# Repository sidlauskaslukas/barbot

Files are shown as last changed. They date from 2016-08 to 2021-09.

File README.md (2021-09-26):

# Barbot

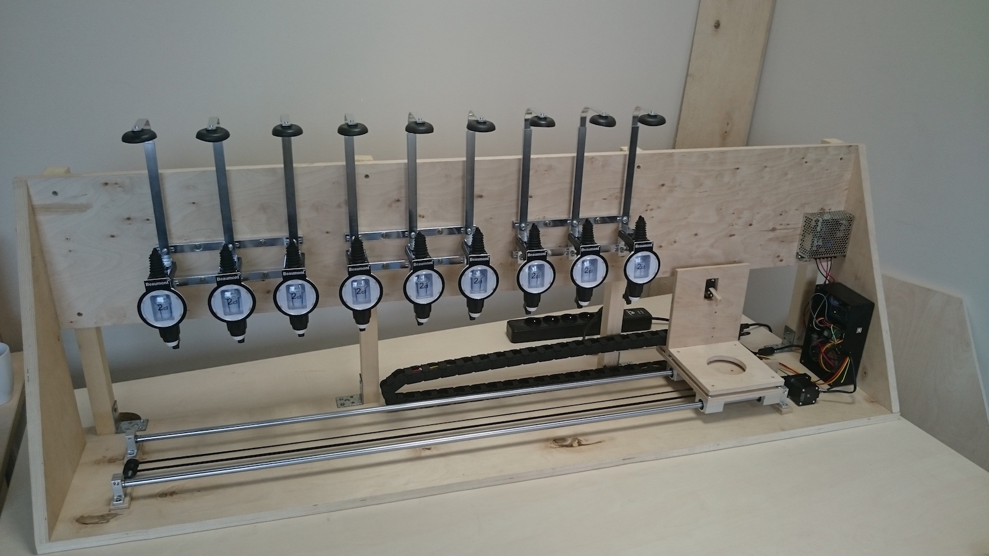
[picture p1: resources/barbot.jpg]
Barbot


Barbot is an open source Arduino cocktail mixing robot controlled with the hybrid mobile app via Bluetooth. It has been designed to hold up to 9 bottles of ingredients for making the cocktails, dispensing the correct amount from each to mix your cocktail of choice.

Cocktails can be chosen using the mobile app (available for iOS and Android) that connects to the Barbot via Bluetooth. In the app you can also enable/disable ingredients, change the position of each ingredient, edit the recipes and change the amount of each ingredient used in the cocktails and so on.

You can check how it works [here](https://youtu.be/1JVnOlu0Daw).

## Getting started

### Requirements
* Node v7.0.0 (I would recommend installing using Nvm [ [installing NVM](https://github.com/nvm-sh/nvm#installing-and-updating) ])
* Android SDK tools [ [installing Cordova requirements](https://cordova.apache.org/docs/en/latest/guide/platforms/android/#installing-the-requirements) ] or Xcode depending on which platform you want to use
* Arduino IDE

### Client
* Clone this repository
* Install Node version 7.0.0 `nvm install 7.0.0`
* Switch to Node version 7.0.0 `nvm use 7.0.0`
* From the client directory, run `npm install`
* Install Cordova 6.3.0 globally `npm install -g cordova@6.3.0`
* Install Ionic CLI 2.2.3 globally `npm install -g ionic@2.2.3`
* Run `ionic serve` in a terminal from the `client` directory
* At this point, Ionic CLI should open the app in your browser

### Barbot
* Clone this repository
* Start the Arduino IDE and open the `Barbot.ino`
* In Arduino IDE, select your board from the `Tools -> Board` menu (right now we're not supporting other boards than Arduino Mega)
* Select the serial port to which Arduino is connected from the `Tools -> Serial Port` menu
* Click the Verify button to see that the code is ok
* Click the Upload button
* If all goes well, that's it

## Required parts
* NEMA 17 stepper motor
* Pololu A4988 stepper driver
* Hitec HS-7955TG servo motor
* Pololu Micro Maestro 6-Channel servo controller
* Bluetooth module HC-05
* GT2 6mm wide timing belt
* GT2 timing pulley 20 teeth 5mm bore
* Timing belt bearing
* 2 x Chrome plated round rail 1200mm x 12mm
* 4 x SK12 12mm bore linear rail shaft support
* 4 x SC12UU aluminium pillow block housing
* 9 x 40ml Beaumont Metrix SL spirit measure
* 3 x Wall 3 bottle rack
* Endstop microswitch
* Arduino Mega 2560
* Cable carrier
* DC-DC converter (12V to 5V)
* AC power supply 12V (6.67A)

### List of 3D parts used in this project
* [NEMA 17 mount](https://www.thingiverse.com/thing:5391)
* [Adjustable belt holder](https://www.thingiverse.com/thing:745934)
* [Idler pulley mount](https://www.thingiverse.com/thing:1225670)

## Wiring diagram
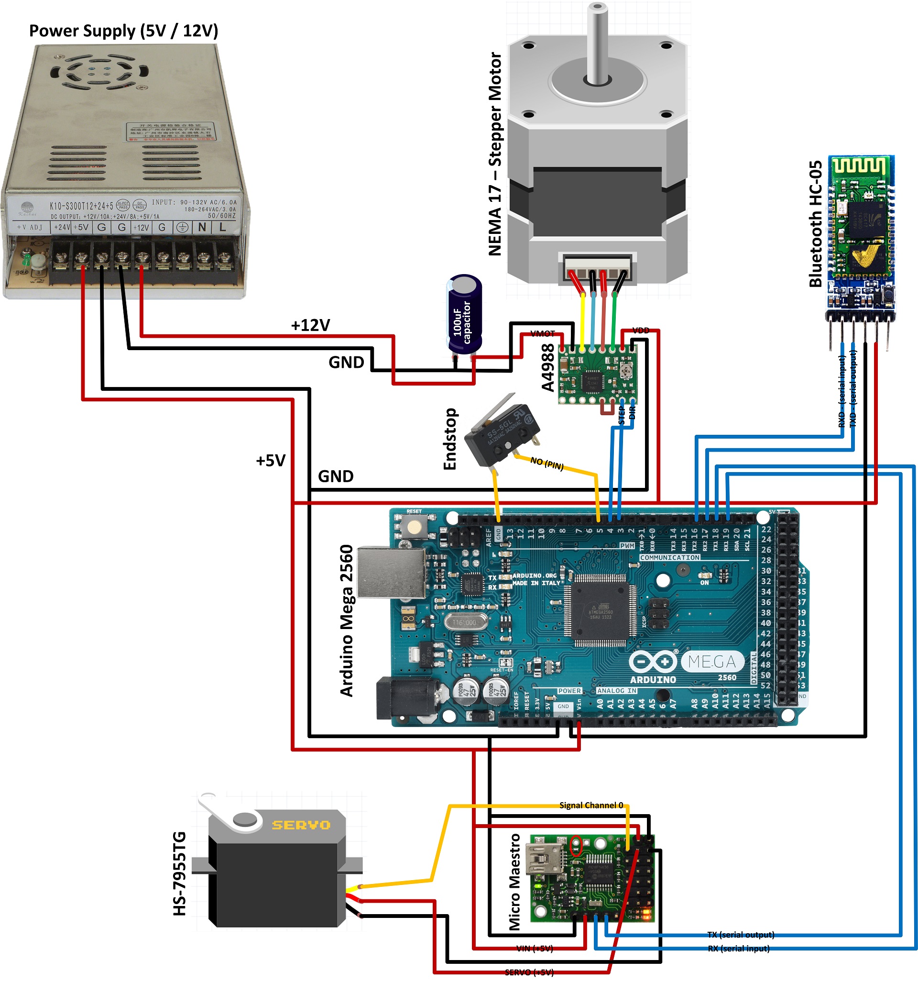
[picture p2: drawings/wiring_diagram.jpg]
Wiring diagram


## Communication
The mobile app and the Barbot communicates over the Serial port using the Bluetooth module HC-05 (with a few small changes, you can use other methods for communication like USB or WiFi too). See all available communication commands below in the "Available commands" section.

## Available commands

Multiple commands can be sent in a single message by separating them with a comma ",". All the commands will be executed one after another in the order in which they're written. The messages must be ended with a newline "\n" character to be run.

**Example**
```
X-4995,F2 H2500 W3000,X-1990,F6 H2300 W2300,H
```

### X: Move X axis

**Usage**  
`Xnnn`

**Parameters**  
Xnnn - The position to move to on the X axis

**Example**  
```
X-4995 ; Move to -4995 position on the X axis
```

### H: Home X axis
**Usage**  
`H`

**Parameters**  
*This command can be used without any parameters*

**Example**  
```
H ; Home the X axis
```

### F: Pour
**Usage**  
`Fnnn Hnnn Wnnn`

**Parameters**  
Fnnn - Times to pour  
Hnnn - Time duration (in ms) to hold dispenser in open position  
Wnnn - Time duration (in ms) to wait till next pour  

**Example**
```
F2 H2500 W3000 ; Pour two times, hold dispenser open for 2500ms and wait for 3000ms between each pour
```

## Additional information
* Dispensers used in this project won't work with liqueur and other thick drinks. You might also have problems with sugary drinks as they stick inner dispenser parts together if you leave the liquid inside the dispenser for hours
* You can use Coca-Cola and other carbonated drinks with these dispensers, but don't forget to make a hole at the bottom of the bottle before mounting the dispenser to the bottle in order to let air get out, otherwise you will have a big fountain. Use empty bottles and fill them later through the holes after mounting the dispensers
* Wash dispensers very well after every use, otherwise the inner dispenser parts will stick together. I would also recommend you to wash them before every use

## Community help
The Barbot Slack group is your first stop for questions and advice about building your own Barbot. You can join the Barbot Slack group [here](https://openbarbot.herokuapp.com).

## Credits and special thanks
* [Visma Lietuva Techies Club](https://www.visma.lt) for support and supplying all needed parts
* [Edmundas Rakauskas](https://github.com/Edmu) for contributing to the project

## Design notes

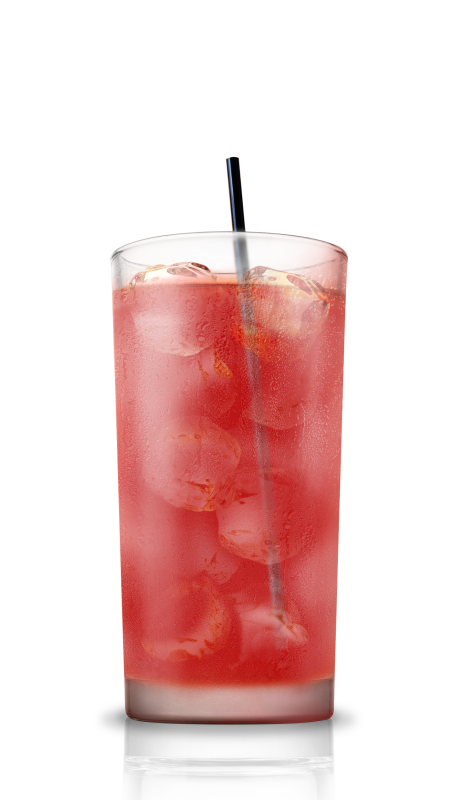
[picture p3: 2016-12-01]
client/src/assets/images/cocktails/jolly_rancher.png

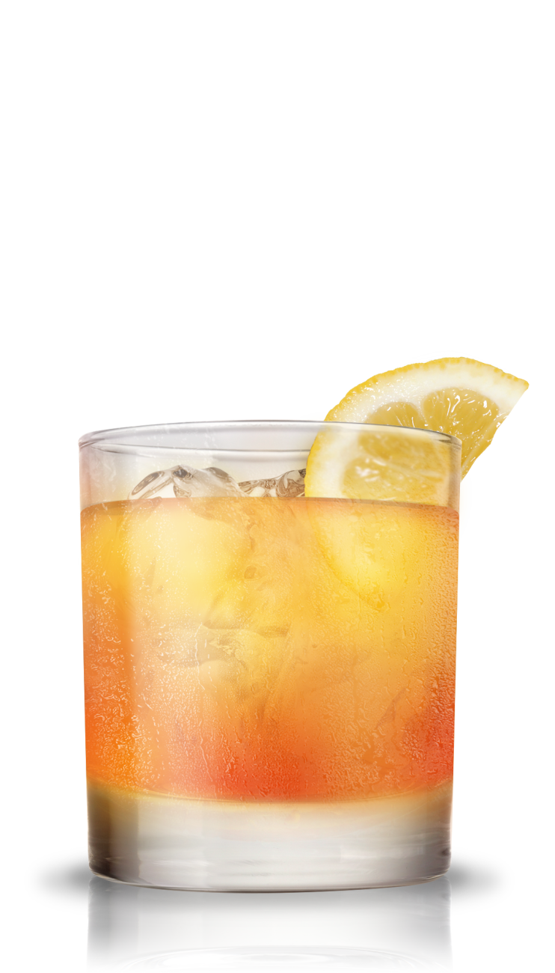
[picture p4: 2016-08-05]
client/src/assets/images/cocktails/cuban_screw.png

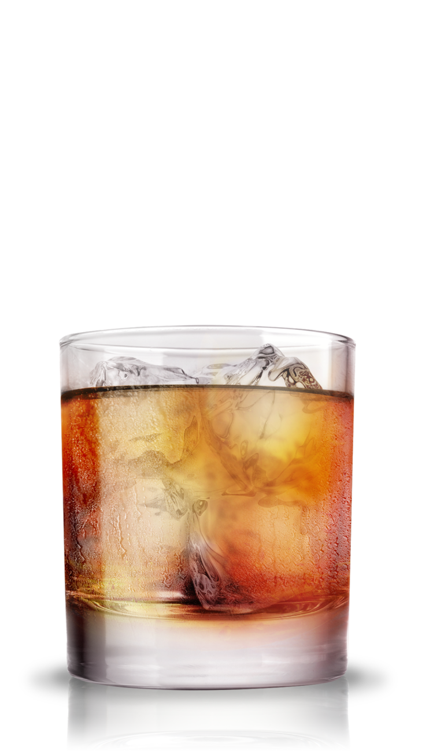
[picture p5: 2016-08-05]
client/src/assets/images/cocktails/vodka_coke.png

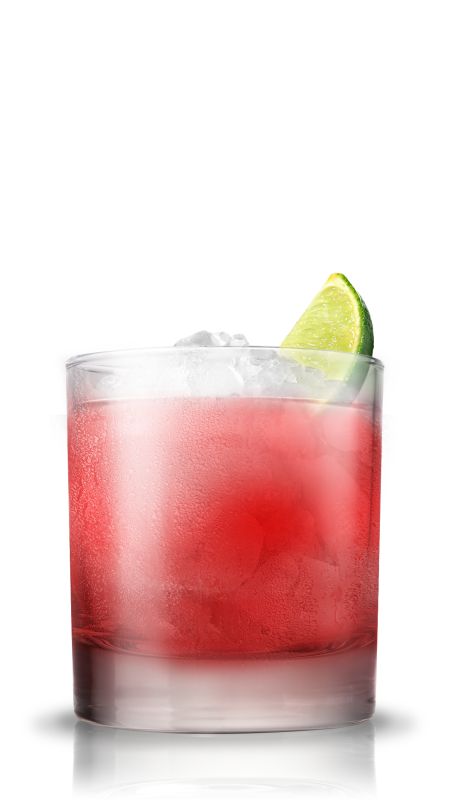
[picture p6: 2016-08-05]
client/src/assets/images/cocktails/sea_breeze.png

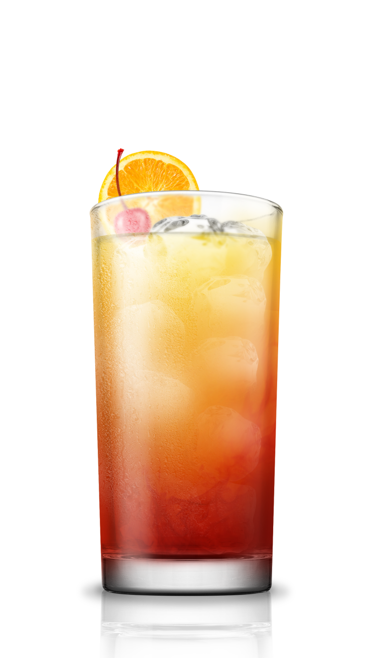
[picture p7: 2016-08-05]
client/src/assets/images/cocktails/malibu_sunrise.png

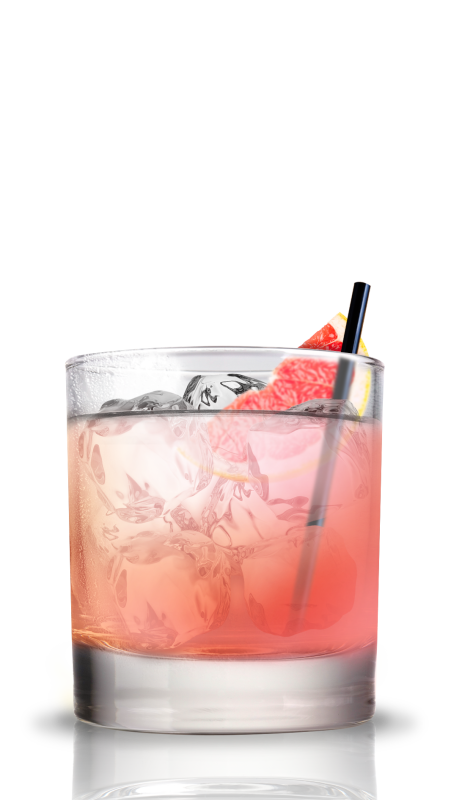
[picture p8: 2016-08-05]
client/src/assets/images/cocktails/greyhound.png

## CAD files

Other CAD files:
drawings/cup_holder.skp

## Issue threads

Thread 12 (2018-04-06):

Direction changes on initialization process

lunanigra, 2018-04-06:
Thanks for your nice barbot setup.

We are facing an issue while driving to the barbot to the initial position. Whenever driving on an obstacle the motor changes the direction (this happens on the setup routine). We don't understand what automatically changes the direction.

Do you know how much power the motor has? We guess that quite some power is needed for moving the glas. So, it looks that the direction is always changing instead of putting real power on the motor.

As everything happens on just few lines of code I'm not really sure what exactly happens.

sidlauskaslukas, 2018-04-10:
@lunanigra have you tried to run the motor standalone? If not, then I would recommend to try this first as it seems this is a hardware problem and not a software.

lunanigra, 2018-04-10:
Hi! I also believe it's not the Arduino code. We did several tests, everything looks ok.

However there is some strange effect. Whenever connecting the cup holder to the motor the motor behaves strange.

We also created some videos showing this effect...
https://youtu.be/cTiT1s3xd5g
https://youtu.be/D-GPr4ozHjQ

Currently I do not understand which hardware part may be defect. I cannot believe the motor is defect... Maybe the A4988? Is there anything we can verify/check?

How to run the motor standalone? Directly connect to power (which voltage)?

sidlauskaslukas, 2018-04-11:
It seems that your driver and the motor is unable to handle the speed and acceleration set in the Configuration file and it's because your drivier is not providing enough current to the motor coils. You can try to decrease those values and see if that works for you.

You can check this video and see how to properly adjust A4988 driver and set the maximum output current according to your stepper motor specs.

Closed 2018-04-12.

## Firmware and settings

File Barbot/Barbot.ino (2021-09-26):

#include "AccelStepper.h"
#include "PololuMaestro.h"
#include "Configuration.h"

String serialBuffer = "";
String actions[TOTAL_ACTIONS];

int counter = 0;
int lastIndex = 0;

AccelStepper stepper(X_INTERFACE_TYPE, X_STEP_PIN, X_DIR_PIN); // Define a stepper and the pins it will use
MicroMaestro maestro(maestroSerial); // Define a servo controller

void setup() {
  Serial.begin(9600); // Serial port for debugging
  maestroSerial.begin(9600); // Servo controller
  Serial2.begin(9600); // Bluetooth module
  stepper.setMaxSpeed(X_MAX_SPEED); // Sets the maximum speed the X axis accelerate up to
  pinMode(X_ENDSTOP_PIN, INPUT_PULLUP); // Initialize endstop pin with the internal pull-up resistor enabled
  homeXAxis(); // Return the X axis to it's home position at the startup
}

void homeXAxis() {
  int endStopState = digitalRead(X_ENDSTOP_PIN);
  
  while (endStopState == HIGH) {
    stepper.moveTo(100);
    stepper.setSpeed(X_HOME_SPEED);
    stepper.runSpeed();
    endStopState = digitalRead(X_ENDSTOP_PIN);
  }

  stepper.moveTo(stepper.currentPosition() - 50);
  while (stepper.distanceToGo() != 0) {
    stepper.setSpeed(X_PARK_SPEED * -1);
    stepper.runSpeed();
  }

  endStopState = digitalRead(X_ENDSTOP_PIN);

  while (endStopState == HIGH) {
    stepper.moveTo(100);
    stepper.setSpeed(X_PARK_SPEED);
    stepper.runSpeed();
    endStopState = digitalRead(X_ENDSTOP_PIN);
  }
  stepper.setCurrentPosition(0);
}

void loop() {
  while(Serial2.available() > 0) {
    char ch = Serial2.read();
    serialBuffer += ch;
    if (ch == '\n') {
      for(int i=0; i<serialBuffer.length(); i++) {
        if(serialBuffer.substring(i, i+1) == ",") {
          actions[counter] = serialBuffer.substring(lastIndex, i);
          lastIndex = i + 1;
          counter++;
        }

        if(i == serialBuffer.length() - 1) {
          actions[counter] = serialBuffer.substring(lastIndex, i);
        }
      }

      for(int z=0; z<TOTAL_ACTIONS; z++) {
        if(actions[z] != "0") {
          parseInput(actions[z]);
        }
      }

      Serial2.println("H");

      for(int y=0; y<TOTAL_ACTIONS; y++) {
        actions[y] = "0";
      }
      
      serialBuffer = "";
      counter = 0;
      lastIndex = 0;

      serialFlush();
    }
  }
}

void parseInput(String input) {
  input.trim();
  byte command = input.charAt(0);

  switch(command) {
    case 'H':
      homeXAxis();
      break;
    case 'X':
      moveXTo(input);
      break;
    case 'F':
      pour(input);
      break;
  }
}

void moveXTo(String input) {
  int pos = input.substring(1).toInt();
  
  Serial.print("X goes to: ");
  Serial.println(pos);
  
  Serial2.println(input);
  
  if(pos < 0 && pos >= X_MAX_POS) {
    stepper.setAcceleration(X_ACCELERATION);
    stepper.moveTo(pos);
      if(pos < stepper.currentPosition()) {
        stepper.setSpeed(-100);
      } else {
        stepper.setSpeed(100);
      }
    while(stepper.distanceToGo() != 0) {
      stepper.run(); 
    }
  } else {
    Serial.println("Position should be between -4995 and 0");
  }
}

void pour(String input) {
  int count = 0; // Pour counter
  int times = 0; // Times to pour
  int holdDuration = 0; // Time duration to hold dispenser in open position
  int waitDuration = 0; // Time duration to wait till next pour
  
  for(int z=0; z<input.length(); z++) {
    byte parameter = input.substring(z, z+1).charAt(0);

    switch(parameter) {
      case 'F':
        times = getParameterValue(input, z);
        break;
      case 'H':
        holdDuration = getParameterValue(input, z);
        break;
      case 'W':
        waitDuration = getParameterValue(input, z);
        break;
    }
  }

  if(holdDuration > 0 && waitDuration > 0) {
    for(int i=0; i<times; i++) {
      maestro.setSpeed(0, SERVO_RAISE_SPEED);
      maestro.setTarget(0, SERVO_MAX_POS);
      delay(holdDuration);
      maestro.setSpeed(0, SERVO_RELEASE_SPEED);
      maestro.setTarget(0, SERVO_MIN_POS);
      if(times - 1 > count) {
        delay(waitDuration);
      } else {
        delay(DELAY_BETWEEN_INGREDIENTS);
      }
      count++;
    }
  } else {
    Serial.println("Hold and wait duration parameters cannot be lower than or equal to 0");
  }
}

int getParameterValue(String input, int z) {
  for(int y=z+1; y<input.length(); y++) {
    if(input.substring(y, y+1) == " ") {
      return input.substring(z+1, y).toInt();
      break;
    }
    if(y == input.length() - 1) {
      return input.substring(z+1, y+1).toInt();
    }
  }
}

void serialFlush() {
  while(Serial2.available()>0) Serial2.read();
}

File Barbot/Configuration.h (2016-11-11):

#ifndef CONFIGURATION_H
#define CONFIGURATION_H

#define maestroSerial SERIAL_PORT_HARDWARE_OPEN

// Stepper driver
#define X_INTERFACE_TYPE 1 // Stepper motor interface type
#define X_STEP_PIN 3 // Stepper driver step pin
#define X_DIR_PIN 4 // Stepper driver dir pin

// Stepper motor
#define X_PARK_SPEED 150 // Parking speed
#define X_HOME_SPEED 700 // Homing speed
#define X_MAX_SPEED 1500 // The maximum speed in steps per second the X axis accelerate up to
#define X_ACCELERATION 3000 // Acceleration/deceleration rate in steps per second per second
#define X_MAX_POS -4995 // The maximum position for the X axis

// Servo motor
#define SERVO_MAX_POS 4120 // Servo hold position
#define SERVO_MIN_POS 6000 // Servo normal position
#define SERVO_RAISE_SPEED 30 // The speed of the servo when travelling from the normal to the hold position
#define SERVO_RELEASE_SPEED 0 // The speed of the servo when travelling from the hold to the normal position

// Endstop
#define X_ENDSTOP_PIN 5 // Endstop pin

// Other
#define TOTAL_ACTIONS 30 // Total number of actions
#define DELAY_BETWEEN_INGREDIENTS 600 // Time duration to wait before travelling to the next ingredient

#endif

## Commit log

2016-08-24 Added barbot cup holder & servo arm models
    [cup_holder.skp, servo_arm.dwg]
2016-11-05 Implemented a filter for filtering recipes by ingredients
2016-11-07 Added hold & wait parameters support, enabled acceleration & deacceleration, increased travel & homing speeds
2016-11-09 Defining constants in the Configuration.h file
    [Configuration.h]
2016-11-09 Added a new constant which defines the total number of actions, other minor changes
    [Configuration.h]
2016-11-11 Commented the code to make it easier to understand, changed the constants
    [Configuration.h]
2017-02-05 Deleted old client files, updated cup holder drawing
    [cup_holder.skp, servo_arm.dwg]
2017-06-29 uploading final wiring diagram
2017-06-30 Added wiring diagram
2021-09-26 clear the input buffer to avoid accidental or repeated action execution
    [Barbot.ino]
